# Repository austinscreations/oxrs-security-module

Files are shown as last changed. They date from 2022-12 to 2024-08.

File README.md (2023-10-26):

# oxrs-security-module
module 8 port pcb that allows for EOL monitoring of security sensors

2023-10-25 version 210 was created to fix p fet issue also updated JLCPCB PCBa files for the modular I2CRJ45 and port PWR extention

this baord is a 4 layer board

port PWR is 2 layers

port PWR extention is a remote switch that allows you to turn ports on and off. the use of a 1.25mm jst cable could eb used instead, simply with pin 5 being GND connect the others to this and a port will be ON

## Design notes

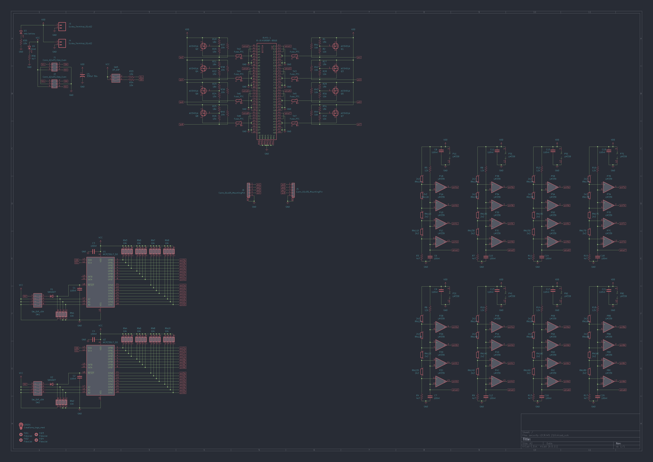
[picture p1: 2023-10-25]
rev 2_1/I2CRJ45 Security 210 modular schematic.jpg

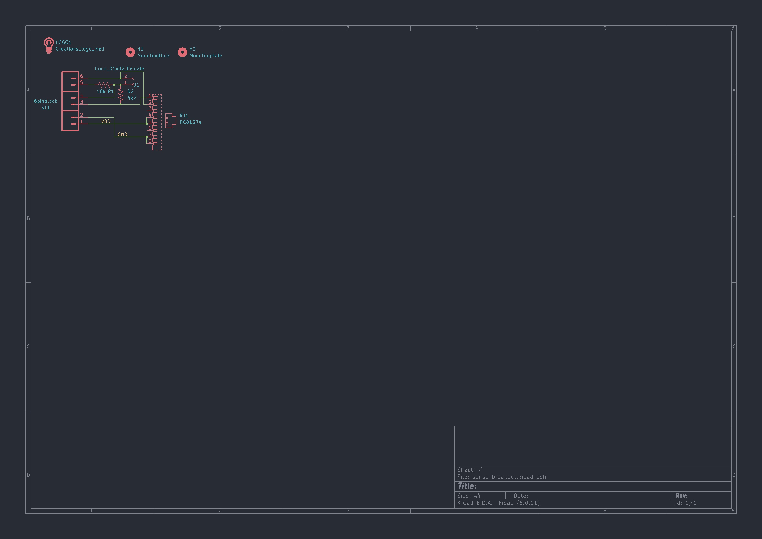
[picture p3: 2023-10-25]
sense breakout/sense breakout schematic.jpg

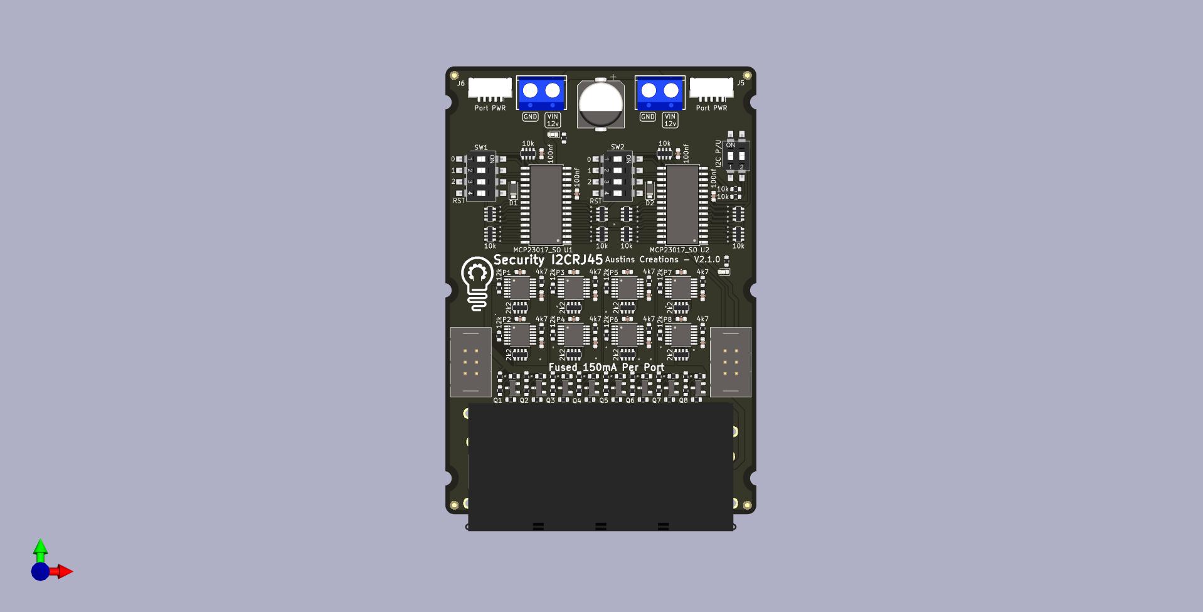
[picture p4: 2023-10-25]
rev 2_1/security I2CRJ45 210 top.jpg

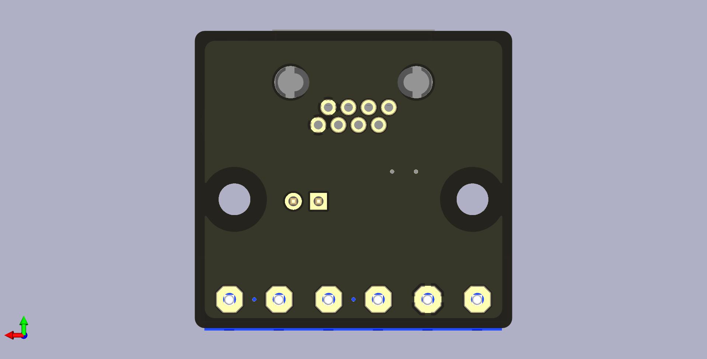
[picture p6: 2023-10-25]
sense breakout/sense breakout bottom.jpg

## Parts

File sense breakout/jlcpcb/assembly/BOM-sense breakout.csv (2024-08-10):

Comment | Designator | Footprint | LCSC
6pinblock | ST1 | 6pinblock | C192781
4k7 | R2 | R_0603_1608Metric | C23162
10k | R1 | R_0603_1608Metric | C25804
Conn_01x02_Female | J1 | PinHeader_1x02_P2.54mm_Vertical | C492401
RC01374 | RJ1 | RC01374 | C385834

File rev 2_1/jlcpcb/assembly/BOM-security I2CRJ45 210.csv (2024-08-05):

Comment | Designator | Footprint | LCSC
2k2 | RN11,RN12,RN13,RN14,RN15,RN16,RN17,RN18 | R_Array_Convex_4x0603 | C12001
Conn_02x03_Odd_Even | J1,J2 | IDC-Header_2x03_P2.54mm_Vertical | C132438
100nf | C1,C10,C11,C12,C13,C14,C15,C16,C17,C18,C19,C2,C20,C21,C3,C4,C6,C7,C8,C9 | C_0603_1608Metric | C14663
AO3401A | Q1,Q2,Q3,Q4,Q5,Q6,Q7,Q8 | SOT-23 | C15127
4k7 | R11,R13,R15,R17,R3,R36,R4,R7,R9 | R_0603_1608Metric | C21190
Conn_01x05_MountingPin | J5,J6 | JST_GH_SM05B-GHS-TB_1x05-1MP_P1.25mm_Horizontal | C225114
12k | R10,R12,R14,R16,R18,R5,R6,R8 | R_0603_1608Metric | C22790
10k | R2,R20,R22,R24,R26,R28,R30,R32,R33,R34,R35,R37,R38,R39,R40,R41,R42,R43,R44 | R_0603_1608Metric | C25804
18k | R1,R19,R21,R23,R25,R27,R29,R31 | R_0603_1608Metric | C25810
2P_DIP | SW5 | 2P_DIP | C2758181
SW_DIP_x04 | SW1,SW2 | 4P_DIP | C2758183
330uf 50v | C5 | CP_Elec_10x10 | C2895745
10k | RN1,RN10,RN2,RN3,RN4,RN5,RN6,RN7,RN8,RN9 | R_Array_Convex_4x0603 | C29718
Screw_Terminal_01x02 | J3,J4 | 2pinblock | C3703
R-RJ45R08P-8000 | RJ45-1 | R-RJ45R08P-8000 | C386760
LM339 | P1,P2,P3,P4,P5,P6,P7,P8 | TSSOP-14_4.4x5mm_P0.65mm | C42184
MCP23017_SO | U1,U2 | SOIC-28W_7.5x17.9mm_P1.27mm | C47023
SM4007 | D1,D2 | D_SOD-123F | C64898
red/yellow | D3 | LED_0603_1608Metric | C72038
blue | D4 | LED_0603_1608Metric | C2286
Fuse_PTC | TH1,TH2,TH3,TH4,TH5,TH6,TH7,TH8 | R_0603_1608Metric | C883087

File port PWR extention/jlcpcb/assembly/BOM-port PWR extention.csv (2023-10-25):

Comment | Designator | Footprint | LCSC
Conn_01x05_MountingPin | J5,J6 | JST_GH_SM05B-GHS-TB_1x05-1MP_P1.25mm_Horizontal | C225114
SW_DIP_x04 | SW1,SW2 | 4P_DIP | C2758183

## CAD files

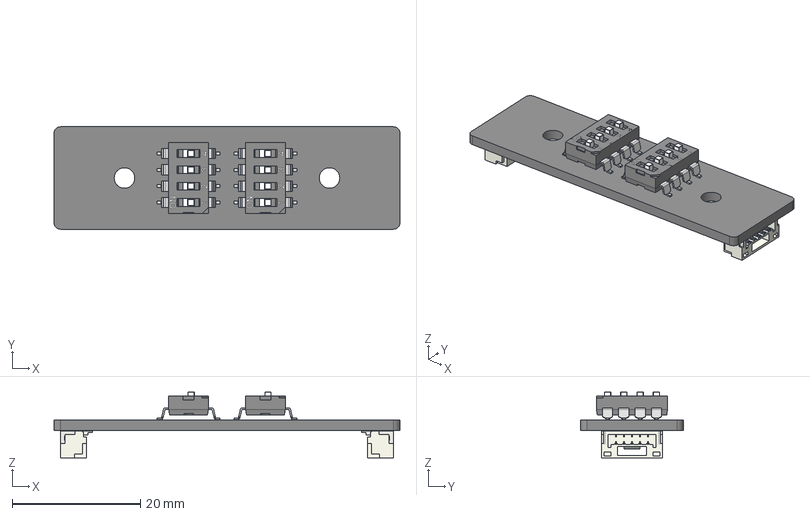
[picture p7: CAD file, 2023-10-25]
port PWR extention/port PWR extention.step
54.0 x 16.0 x 10.3 mm
_autosave-port PWR extention PCB

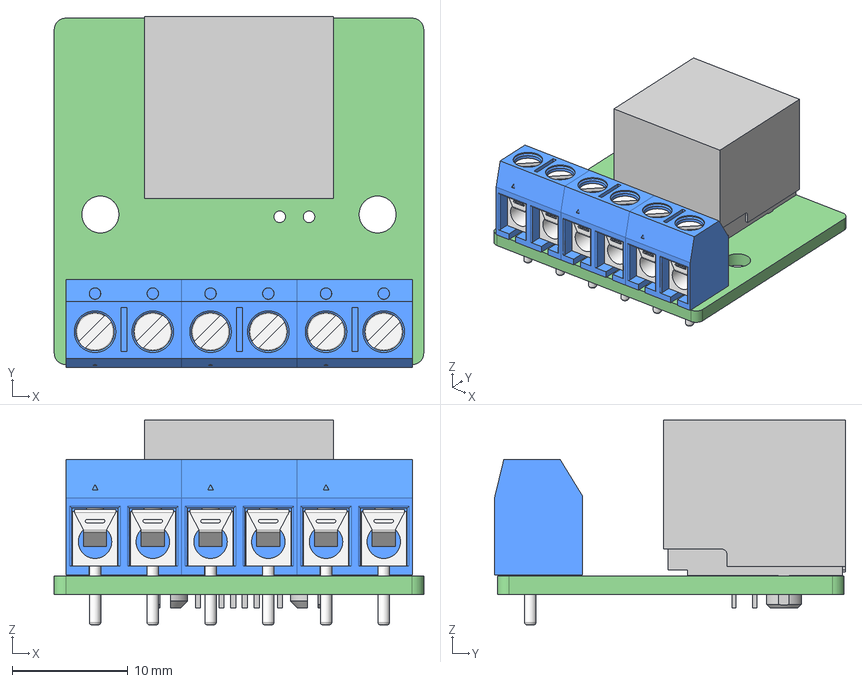
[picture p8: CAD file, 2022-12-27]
sense breakout/sense breakout.step
32.0 x 30.4 x 17.7 mm
sense breakout PCB

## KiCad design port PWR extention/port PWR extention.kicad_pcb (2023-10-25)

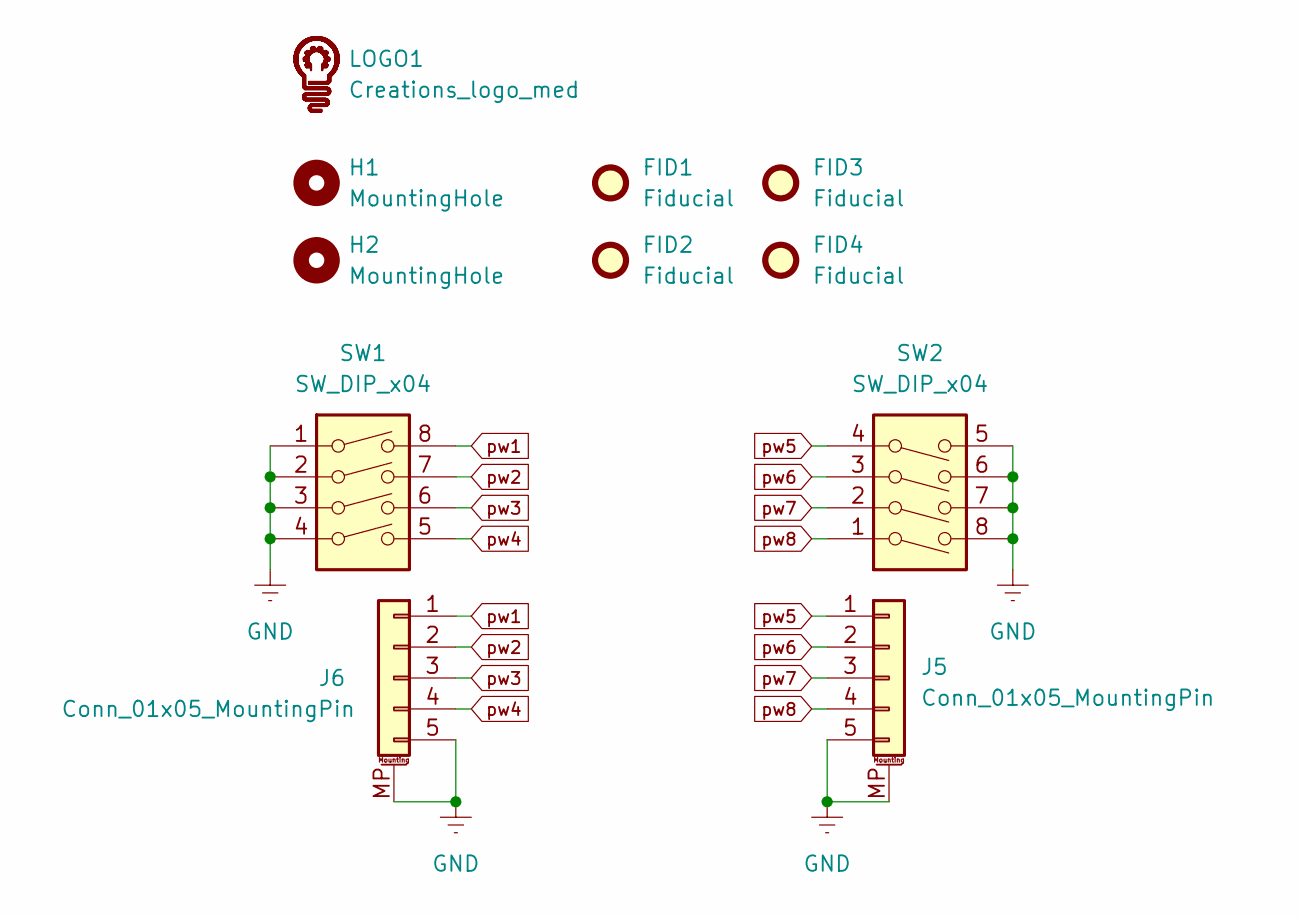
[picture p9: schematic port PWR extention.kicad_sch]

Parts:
FID1, FID2, FID3, FID4: Fiducial; Fiducial_1mm_Mask2mm
H1, H2: MountingHole; MountingHole_3.2mm_M3
J5, J6: Conn_01x05_MountingPin; JST_GH_SM05B-GHS-TB_1x05-1MP_P1.25mm_Horizontal; LCSC C225114
LOGO1: Creations_logo_med; Creations logo med
SW1, SW2: SW_DIP_x04; 4P_DIP; LCSC C2758183

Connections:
GNDREF: J5.5, J5.MP (MountPin), J6.5, J6.MP (MountPin), SW1.1, SW1.2, SW1.3, SW1.4, SW2.5, SW2.6, SW2.7, SW2.8
pw1: J6.1, SW1.8
pw2: J6.2, SW1.7
pw3: J6.3, SW1.6
pw4: J6.4, SW1.5
pw5: J5.1, SW2.4
pw6: J5.2, SW2.3
pw7: J5.3, SW2.2
pw8: J5.4, SW2.1

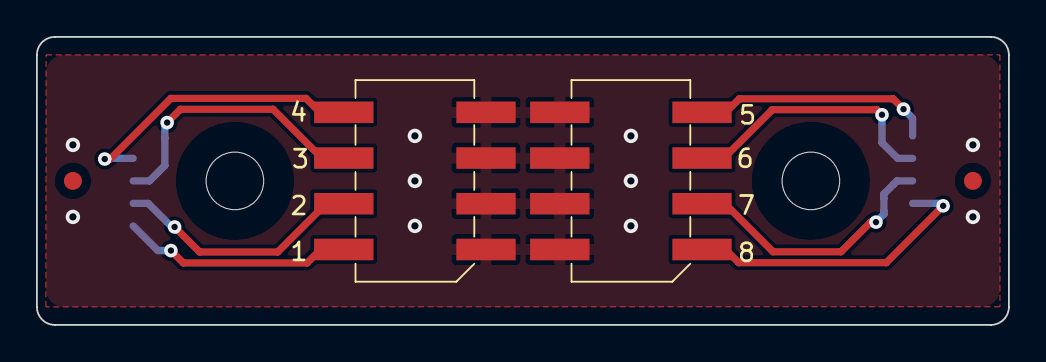
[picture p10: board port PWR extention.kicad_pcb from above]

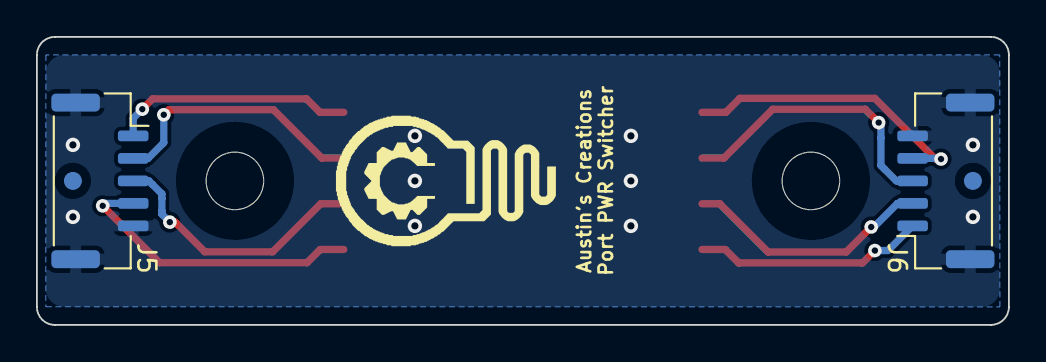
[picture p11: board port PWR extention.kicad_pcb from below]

Board: 2 copper layers, 54.0 x 16.0 mm, 11 parts (5 on the bottom side), 9 nets.

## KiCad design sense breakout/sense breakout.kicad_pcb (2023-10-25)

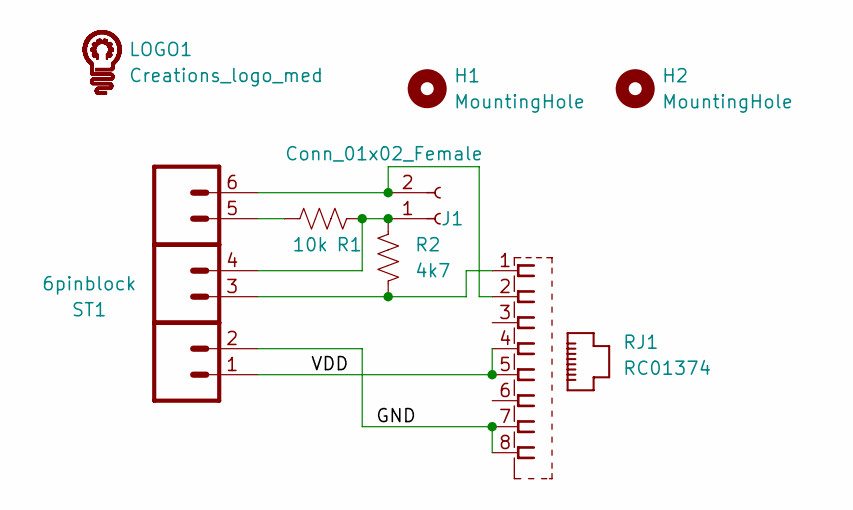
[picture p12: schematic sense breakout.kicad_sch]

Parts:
H1, H2: MountingHole; MountingHole_3.2mm_M3
J1: Conn_01x02_Female; PinHeader_1x02_P2.54mm_Vertical; LCSC C2829889
LOGO1: Creations_logo_med; Creations logo med
R1: 10k; R_0603_1608Metric; LCSC C25804
R2: 4k7; R_0603_1608Metric; LCSC C23162
RJ1: RC01374; LCSC C385834
ST1: 6pinblock; LCSC C192781

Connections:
/GND: RJ1.7, RJ1.8, ST1.2
/VDD: RJ1.4, RJ1.5, ST1.1
unnamed: J1.1, R1.1, R2.1, ST1.4
unnamed: J1.2, RJ1.2, ST1.6
unnamed: R1.2, ST1.5
unnamed: R2.2, RJ1.1, ST1.3

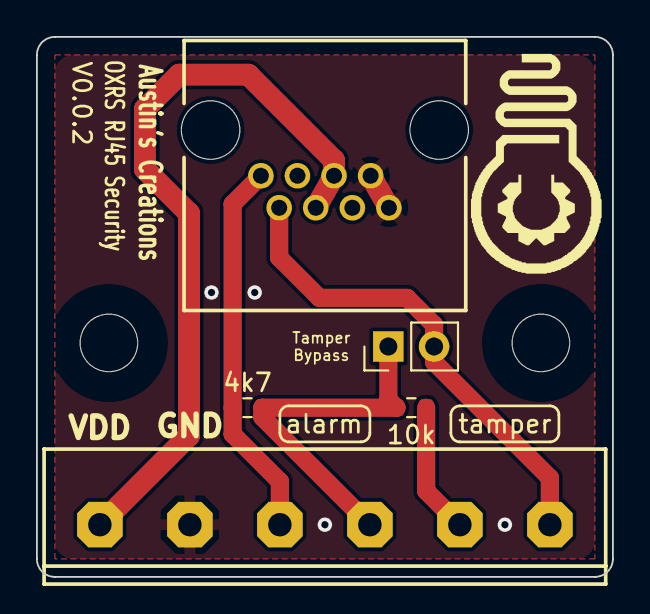
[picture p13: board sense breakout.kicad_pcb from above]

Board: 2 copper layers, 32.0 x 30.0 mm, 8 parts (0 on the bottom side), 6 nets.

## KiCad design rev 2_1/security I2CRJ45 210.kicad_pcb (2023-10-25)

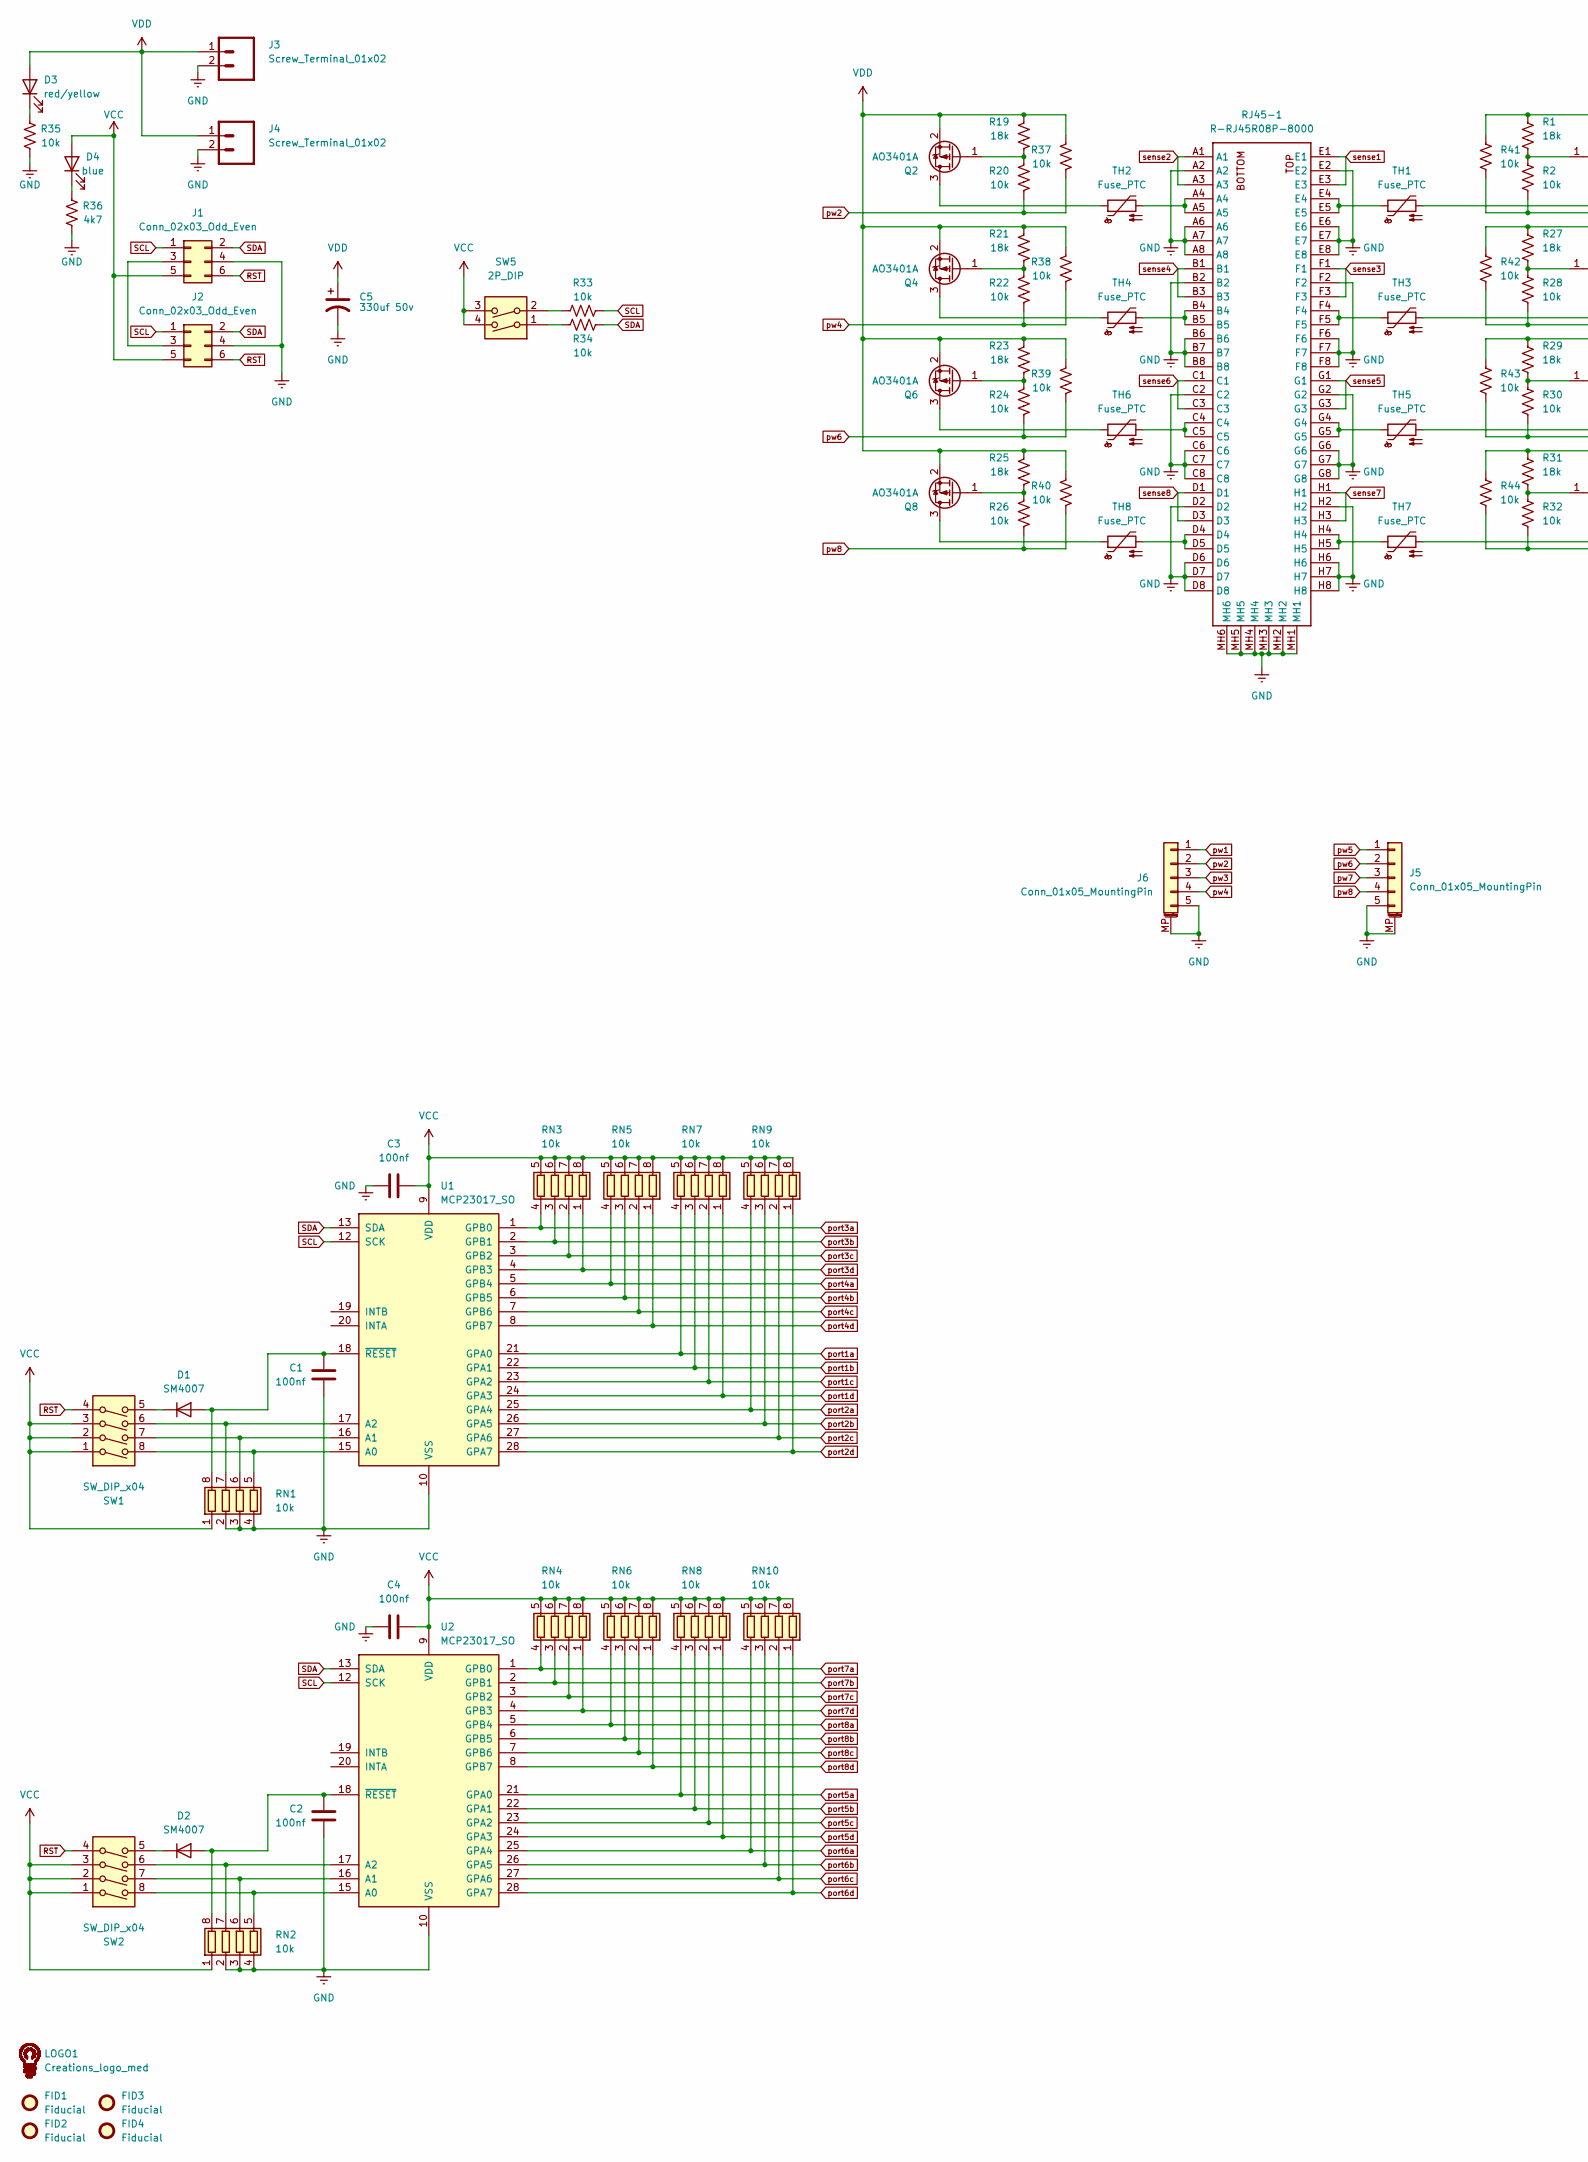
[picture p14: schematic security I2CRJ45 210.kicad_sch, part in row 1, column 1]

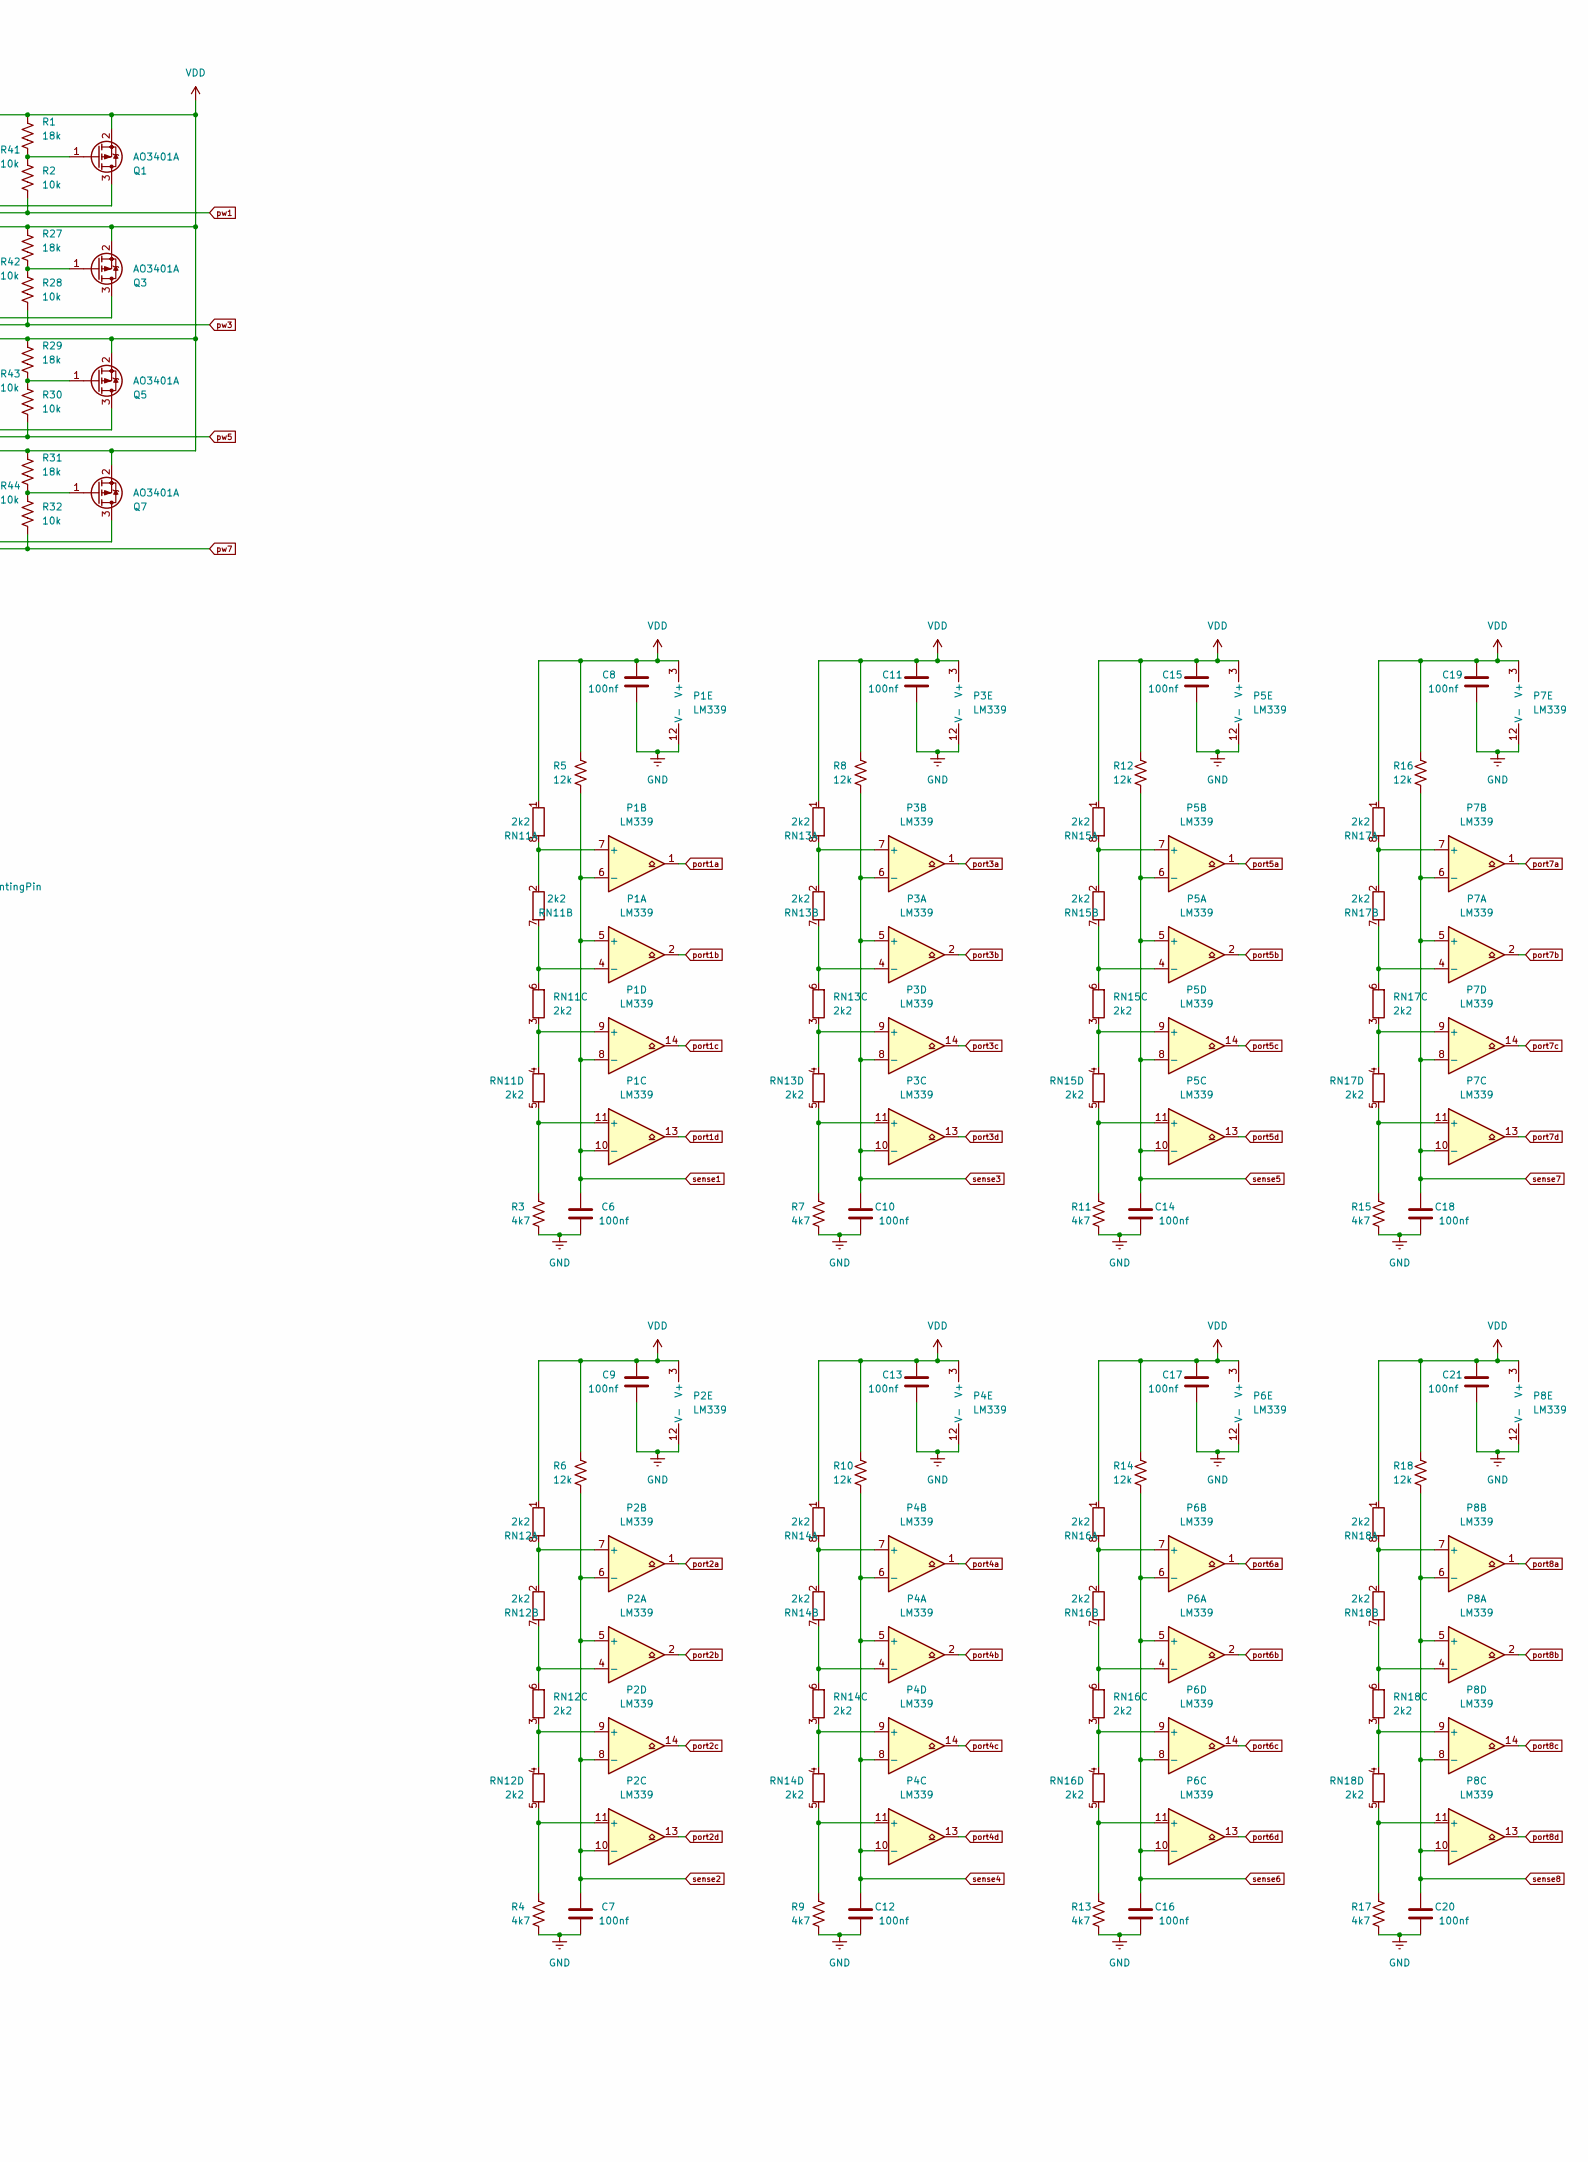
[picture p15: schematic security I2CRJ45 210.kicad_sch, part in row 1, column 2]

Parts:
C1, C2, C3, C4, C6, C7, C8, C9, C10, C11, C12, C13, C14, C15, C16, C17, C18, C19, C20, C21: 100nf; C_0603_1608Metric; LCSC C14663
C5: 330uf 50v; CP_Elec_10x10; LCSC C2895745
D1, D2: SM4007; D_SOD-123F; LCSC C64898
D3: red/yellow; LED_0603_1608Metric; LCSC C72038
D4: blue; LED_0603_1608Metric; LCSC C72041
FID1, FID2, FID3, FID4: Fiducial; Fiducial_1mm_Mask2mm
J1, J2: Conn_02x03_Odd_Even; IDC-Header_2x03_P2.54mm_Vertical; LCSC C132438
J3, J4: Screw_Terminal_01x02; 2pinblock; LCSC C3703
J5, J6: Conn_01x05_MountingPin; JST_GH_SM05B-GHS-TB_1x05-1MP_P1.25mm_Horizontal; LCSC C225114
LOGO1: Creations_logo_med; Creations logo med
P1, P2, P3, P4, P5, P6, P7, P8: LM339; TSSOP-14_4.4x5mm_P0.65mm; part # 511-LM339DT; LCSC C42184
Q1, Q2, Q3, Q4, Q5, Q6, Q7, Q8: AO3401A; SOT-23; LCSC C15127
R1, R19, R21, R23, R25, R27, R29, R31: 18k; R_0603_1608Metric; LCSC C25810
R2, R20, R22, R24, R26, R28, R30, R32, R33, R34, R35, R37, R38, R39, R40, R41, R42, R43, R44: 10k; R_0603_1608Metric; LCSC C25804
R3, R4, R7, R9, R11, R13, R15, R17, R36: 4k7; R_0603_1608Metric; LCSC C21190
R5, R6, R8, R10, R12, R14, R16, R18: 12k; R_0603_1608Metric; LCSC C22790
RJ45-1: R-RJ45R08P-8000; LCSC C386760
RN1, RN2, RN3, RN4, RN5, RN6, RN7, RN8, RN9, RN10: 10k; R_Array_Convex_4x0603; LCSC C29718
RN11, RN12, RN13, RN14, RN15, RN16, RN17, RN18: 2k2; R_Array_Convex_4x0603; LCSC C12001
SW1, SW2: SW_DIP_x04; 4P_DIP; LCSC C2758183
SW5: 2P_DIP; LCSC C2758181
TH1, TH2, TH3, TH4, TH5, TH6, TH7, TH8: Fuse_PTC; R_0603_1608Metric; LCSC C883087
U1, U2: MCP23017_SO; SOIC-28W_7.5x17.9mm_P1.27mm; LCSC C47023

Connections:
GNDREF: C1.2, C2.2, C3.1, C4.1, C5.2, C6.2, C7.2, C8.2, C9.2, C10.2, C11.2, C12.2, C13.2, C14.2, C15.2, C16.2, C17.2, C18.2, C19.2, C20.2, C21.2, J1.4, J2.4, J3.2, J4.2, J5.5, J5.MP (MountPin), J6.5, J6.MP (MountPin), P1.12 (V-), P2.12 (V-), P3.12 (V-), P4.12 (V-), P5.12 (V-), P6.12 (V-), P7.12 (V-), P8.12 (V-), R3.2, R4.2, R7.2, R9.2, R11.2, R13.2, R15.2, R17.2, R35.2, R36.2, RJ45-1.A2, RJ45-1.A6, RJ45-1.A7, RJ45-1.A8, RJ45-1.B2, RJ45-1.B6, RJ45-1.B7, RJ45-1.B8, RJ45-1.C2, RJ45-1.C6, RJ45-1.C7, RJ45-1.C8, RJ45-1.D2, RJ45-1.D6, RJ45-1.D7, RJ45-1.D8, RJ45-1.E2, RJ45-1.E6, RJ45-1.E7, RJ45-1.E8, RJ45-1.F2, RJ45-1.F6, RJ45-1.F7, RJ45-1.F8, RJ45-1.G2, RJ45-1.G6, RJ45-1.G7, RJ45-1.G8, RJ45-1.H2, RJ45-1.H6, RJ45-1.H7, RJ45-1.H8, RJ45-1.MH1, RJ45-1.MH2, RJ45-1.MH3, RJ45-1.MH4, RJ45-1.MH5, RJ45-1.MH6, RN1.2 (R2.1), RN1.3 (R3.1), RN1.4 (R4.1), RN2.2 (R2.1), RN2.3 (R3.1), RN2.4 (R4.1), U1.10 (VSS), U2.10 (VSS)
unnamed: C1.1, D1.2 (A), RN1.8 (R1.2), U1.18 (~RESET)
unnamed: C2.1, D2.2 (A), RN2.8 (R1.2), U2.18 (~RESET)
unnamed: D1.1 (K), SW1.5
unnamed: D2.1 (K), SW2.5
unnamed: D3.1 (K), R35.1
unnamed: D4.1 (K), R36.1
unnamed: J1.3, J2.3
unnamed: P1.4 (-), RN11.6 (R3.2), RN11.7 (R2.2)
unnamed: P1.7 (+), RN11.2 (R2.1), RN11.8 (R1.2)
unnamed: P1.9 (+), RN11.3 (R3.1), RN11.4 (R4.1)
unnamed: P1.11 (+), R3.1, RN11.5 (R4.2)
unnamed: P2.4 (-), RN12.6 (R3.2), RN12.7 (R2.2)
unnamed: P2.7 (+), RN12.2 (R2.1), RN12.8 (R1.2)
unnamed: P2.9 (+), RN12.3 (R3.1), RN12.4 (R4.1)
unnamed: P2.11 (+), R4.1, RN12.5 (R4.2)
unnamed: P3.4 (-), RN13.6 (R3.2), RN13.7 (R2.2)
unnamed: P3.7 (+), RN13.2 (R2.1), RN13.8 (R1.2)
unnamed: P3.9 (+), RN13.3 (R3.1), RN13.4 (R4.1)
unnamed: P3.11 (+), R7.1, RN13.5 (R4.2)
unnamed: P4.4 (-), RN14.6 (R3.2), RN14.7 (R2.2)
unnamed: P4.7 (+), RN14.2 (R2.1), RN14.8 (R1.2)
unnamed: P4.9 (+), RN14.3 (R3.1), RN14.4 (R4.1)
unnamed: P4.11 (+), R9.1, RN14.5 (R4.2)
unnamed: P5.4 (-), RN15.6 (R3.2), RN15.7 (R2.2)
unnamed: P5.7 (+), RN15.2 (R2.1), RN15.8 (R1.2)
unnamed: P5.9 (+), RN15.3 (R3.1), RN15.4 (R4.1)
unnamed: P5.11 (+), R11.1, RN15.5 (R4.2)
unnamed: P6.4 (-), RN16.6 (R3.2), RN16.7 (R2.2)
unnamed: P6.7 (+), RN16.2 (R2.1), RN16.8 (R1.2)
unnamed: P6.9 (+), RN16.3 (R3.1), RN16.4 (R4.1)
unnamed: P6.11 (+), R13.1, RN16.5 (R4.2)
unnamed: P7.4 (-), RN17.6 (R3.2), RN17.7 (R2.2)
unnamed: P7.7 (+), RN17.2 (R2.1), RN17.8 (R1.2)
unnamed: P7.9 (+), RN17.3 (R3.1), RN17.4 (R4.1)
unnamed: P7.11 (+), R15.1, RN17.5 (R4.2)
unnamed: P8.4 (-), RN18.6 (R3.2), RN18.7 (R2.2)
unnamed: P8.7 (+), RN18.2 (R2.1), RN18.8 (R1.2)
unnamed: P8.9 (+), RN18.3 (R3.1), RN18.4 (R4.1)
unnamed: P8.11 (+), R17.1, RN18.5 (R4.2)
unnamed: Q1.1 (G), R1.2, R2.1
unnamed: Q1.3 (D), TH1.2
unnamed: Q2.1 (G), R19.2, R20.1
unnamed: Q2.3 (D), TH2.1
unnamed: Q3.1 (G), R27.2, R28.1
unnamed: Q3.3 (D), TH3.2
unnamed: Q4.1 (G), R21.2, R22.1
unnamed: Q4.3 (D), TH4.1
unnamed: Q5.1 (G), R29.2, R30.1
unnamed: Q5.3 (D), TH5.2
unnamed: Q6.1 (G), R23.2, R24.1
unnamed: Q6.3 (D), TH6.1
unnamed: Q7.1 (G), R31.2, R32.1
unnamed: Q7.3 (D), TH7.2
unnamed: Q8.1 (G), R25.2, R26.1
unnamed: Q8.3 (D), TH8.1
unnamed: R33.1, SW5.2
unnamed: R34.1, SW5.1
unnamed: RJ45-1.A4, RJ45-1.A5, TH2.2
unnamed: RJ45-1.B4, RJ45-1.B5, TH4.2
unnamed: RJ45-1.C4, RJ45-1.C5, TH6.2
unnamed: RJ45-1.D4, RJ45-1.D5, TH8.2
unnamed: RJ45-1.E4, RJ45-1.E5, TH1.1
unnamed: RJ45-1.F4, RJ45-1.F5, TH3.1
unnamed: RJ45-1.G4, RJ45-1.G5, TH5.1
unnamed: RJ45-1.H4, RJ45-1.H5, TH7.1
unnamed: RN1.5 (R4.2), SW1.8, U1.15 (A0)
unnamed: RN1.6 (R3.2), SW1.7, U1.16 (A1)
unnamed: RN1.7 (R2.2), SW1.6, U1.17 (A2)
unnamed: RN2.5 (R4.2), SW2.8, U2.15 (A0)
unnamed: RN2.6 (R3.2), SW2.7, U2.16 (A1)
unnamed: RN2.7 (R2.2), SW2.6, U2.17 (A2)
RST: J1.6, J2.6, SW1.4, SW2.4
SCL: J1.1, J2.1, R33.2, U1.12 (SCK), U2.12 (SCK)
SDA: J1.2, J2.2, R34.2, U1.13 (SDA), U2.13 (SDA)
VCC: C3.2, C4.2, D4.2 (A), J1.5, J2.5, RN1.1 (R1.1), RN2.1 (R1.1), RN3.5 (R4.2), RN3.6 (R3.2), RN3.7 (R2.2), RN3.8 (R1.2), RN4.5 (R4.2), RN4.6 (R3.2), RN4.7 (R2.2), RN4.8 (R1.2), RN5.5 (R4.2), RN5.6 (R3.2), RN5.7 (R2.2), RN5.8 (R1.2), RN6.5 (R4.2), RN6.6 (R3.2), RN6.7 (R2.2), RN6.8 (R1.2), RN7.5 (R4.2), RN7.6 (R3.2), RN7.7 (R2.2), RN7.8 (R1.2), RN8.5 (R4.2), RN8.6 (R3.2), RN8.7 (R2.2), RN8.8 (R1.2), RN9.5 (R4.2), RN9.6 (R3.2), RN9.7 (R2.2), RN9.8 (R1.2), RN10.5 (R4.2), RN10.6 (R3.2), RN10.7 (R2.2), RN10.8 (R1.2), SW1.1, SW1.2, SW1.3, SW2.1, SW2.2, SW2.3, SW5.3, SW5.4, U1.9 (VDD), U2.9 (VDD)
VDD: C5.1, C8.1, C9.1, C11.1, C13.1, C15.1, C17.1, C19.1, C21.1, D3.2 (A), J3.1, J4.1, P1.3 (V+), P2.3 (V+), P3.3 (V+), P4.3 (V+), P5.3 (V+), P6.3 (V+), P7.3 (V+), P8.3 (V+), Q1.2 (S), Q2.2 (S), Q3.2 (S), Q4.2 (S), Q5.2 (S), Q6.2 (S), Q7.2 (S), Q8.2 (S), R1.1, R5.1, R6.1, R8.1, R10.1, R12.1, R14.1, R16.1, R18.1, R19.1, R21.1, R23.1, R25.1, R27.1, R29.1, R31.1, R37.1, R38.1, R39.1, R40.1, R41.1, R42.1, R43.1, R44.1, RN11.1 (R1.1), RN12.1 (R1.1), RN13.1 (R1.1), RN14.1 (R1.1), RN15.1 (R1.1), RN16.1 (R1.1), RN17.1 (R1.1), RN18.1 (R1.1)
port1a: P1.1, RN7.4 (R4.1), U1.21 (GPA0)
port1b: P1.2, RN7.3 (R3.1), U1.22 (GPA1)
port1c: P1.14, RN7.2 (R2.1), U1.23 (GPA2)
port1d: P1.13, RN7.1 (R1.1), U1.24 (GPA3)
port2a: P2.1, RN9.4 (R4.1), U1.25 (GPA4)
port2b: P2.2, RN9.3 (R3.1), U1.26 (GPA5)
port2c: P2.14, RN9.2 (R2.1), U1.27 (GPA6)
port2d: P2.13, RN9.1 (R1.1), U1.28 (GPA7)
port3a: P3.1, RN3.4 (R4.1), U1.1 (GPB0)
port3b: P3.2, RN3.3 (R3.1), U1.2 (GPB1)
port3c: P3.14, RN3.2 (R2.1), U1.3 (GPB2)
port3d: P3.13, RN3.1 (R1.1), U1.4 (GPB3)
port4a: P4.1, RN5.4 (R4.1), U1.5 (GPB4)
port4b: P4.2, RN5.3 (R3.1), U1.6 (GPB5)
port4c: P4.14, RN5.2 (R2.1), U1.7 (GPB6)
port4d: P4.13, RN5.1 (R1.1), U1.8 (GPB7)
port5a: P5.1, RN8.4 (R4.1), U2.21 (GPA0)
port5b: P5.2, RN8.3 (R3.1), U2.22 (GPA1)
port5c: P5.14, RN8.2 (R2.1), U2.23 (GPA2)
port5d: P5.13, RN8.1 (R1.1), U2.24 (GPA3)
port6a: P6.1, RN10.4 (R4.1), U2.25 (GPA4)
port6b: P6.2, RN10.3 (R3.1), U2.26 (GPA5)
port6c: P6.14, RN10.2 (R2.1), U2.27 (GPA6)
port6d: P6.13, RN10.1 (R1.1), U2.28 (GPA7)
port7a: P7.1, RN4.4 (R4.1), U2.1 (GPB0)
port7b: P7.2, RN4.3 (R3.1), U2.2 (GPB1)
port7c: P7.14, RN4.2 (R2.1), U2.3 (GPB2)
port7d: P7.13, RN4.1 (R1.1), U2.4 (GPB3)
port8a: P8.1, RN6.4 (R4.1), U2.5 (GPB4)
port8b: P8.2, RN6.3 (R3.1), U2.6 (GPB5)
port8c: P8.14, RN6.2 (R2.1), U2.7 (GPB6)
port8d: P8.13, RN6.1 (R1.1), U2.8 (GPB7)
pw1: J6.1, R2.2, R41.2
pw2: J6.2, R20.2, R37.2
pw3: J6.3, R28.2, R42.2
pw4: J6.4, R22.2, R38.2
pw5: J5.1, R30.2, R43.2
pw6: J5.2, R24.2, R39.2
pw7: J5.3, R32.2, R44.2
pw8: J5.4, R26.2, R40.2
sense1: C6.1, P1.5 (+), P1.6 (-), P1.8 (-), P1.10 (-), R5.2, RJ45-1.E1, RJ45-1.E3
sense2: C7.1, P2.5 (+), P2.6 (-), P2.8 (-), P2.10 (-), R6.2, RJ45-1.A1, RJ45-1.A3
sense3: C10.1, P3.5 (+), P3.6 (-), P3.8 (-), P3.10 (-), R8.2, RJ45-1.F1, RJ45-1.F3
sense4: C12.1, P4.5 (+), P4.6 (-), P4.8 (-), P4.10 (-), R10.2, RJ45-1.B1, RJ45-1.B3
sense5: C14.1, P5.5 (+), P5.6 (-), P5.8 (-), P5.10 (-), R12.2, RJ45-1.G1, RJ45-1.G3
sense6: C16.1, P6.5 (+), P6.6 (-), P6.8 (-), P6.10 (-), R14.2, RJ45-1.C1, RJ45-1.C3
sense7: C18.1, P7.5 (+), P7.6 (-), P7.8 (-), P7.10 (-), R16.2, RJ45-1.H1, RJ45-1.H3
sense8: C20.1, P8.5 (+), P8.6 (-), P8.8 (-), P8.10 (-), R18.2, RJ45-1.D1, RJ45-1.D3

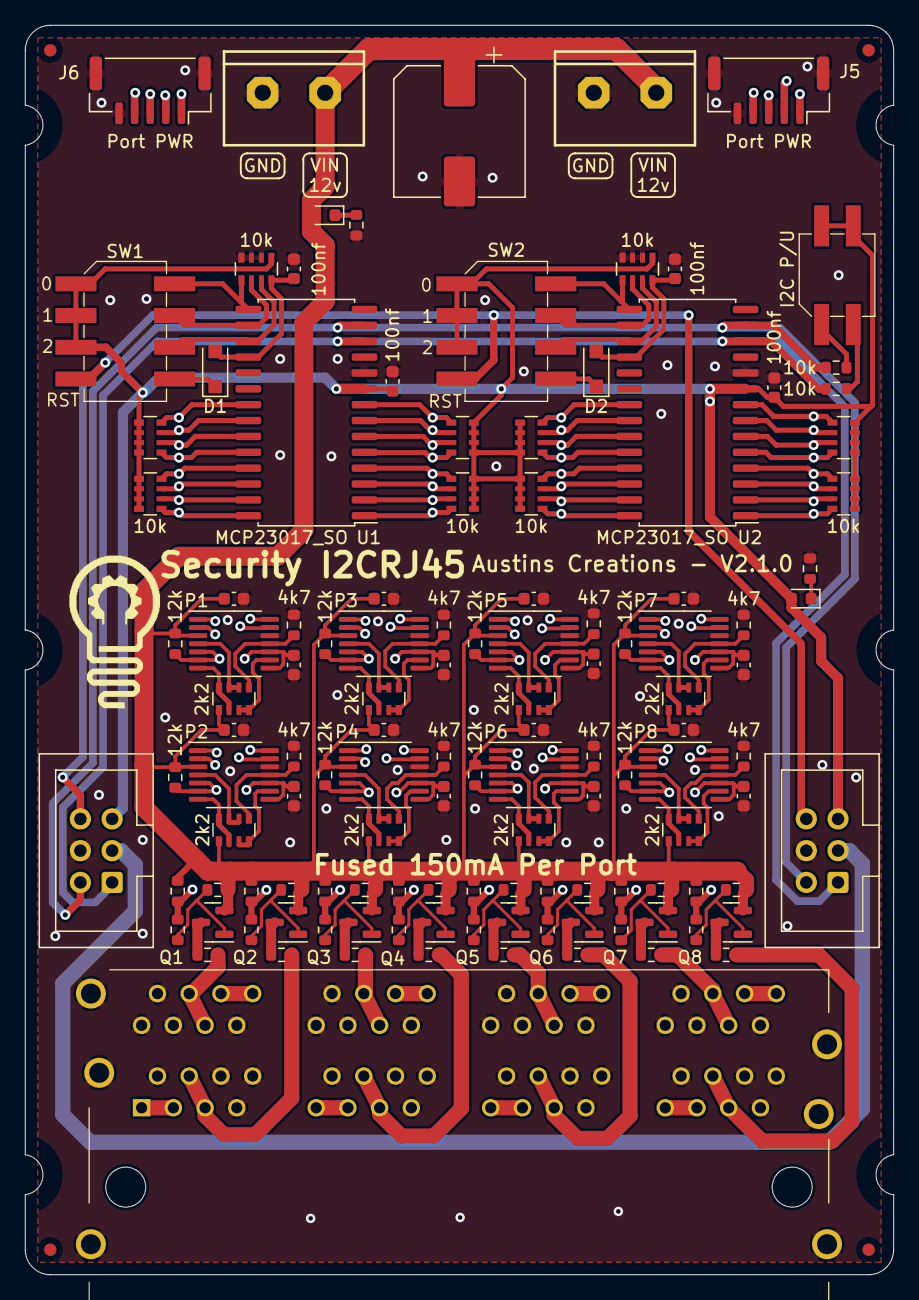
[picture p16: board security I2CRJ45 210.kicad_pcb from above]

Board: 4 copper layers, 69.5 x 100.0 mm, 128 parts (0 on the bottom side), 125 nets.

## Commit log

2022-08-18 add photos of PCBs
2022-08-18 PCB files for security module
    [BOM-security module.csv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]
2022-08-18 pcb files for port power extension control
    [BOM-port PWR extention.csv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]
2023-05-14 Adding p fet warning
2024-08-05 update d4 led to use JLCPCB part C2286
    [BOM-security I2CRJ45 210.csv]
2024-08-09 update j1 part to C492401 update rotation and position for j1
    [BOM-sense breakout.csv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]
